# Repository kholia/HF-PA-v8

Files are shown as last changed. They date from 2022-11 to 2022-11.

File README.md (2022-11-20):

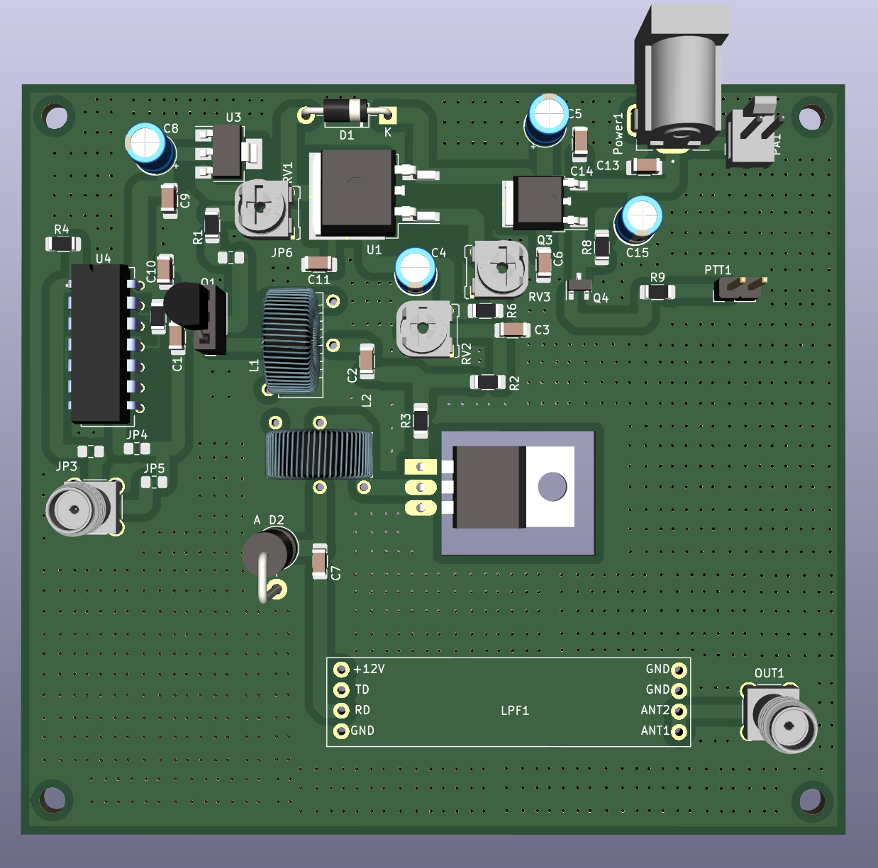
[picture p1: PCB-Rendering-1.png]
PCB Rendering


This work improves upon https://github.com/kholia/HF-PA-v6.

Central idea:

When driven by a Si5351 directly, the output of BS170 is mere 7 to 8 Vpp at 28
MHz.

When driven by a hex-inverter, the output of BS170 easily reaches 13 Vpp at 28
MHz.

This higher BS170 driver output is likely to produce better results (more power
and efficiency) from the IRF510 final @ 28 MHz.

Long-term TODO: Convert all components to SMD. The legs of the THT components
can be bent and fit on top of SMD pads!

- Pots - Bend legs

- Hex-inverter - Get the SMD version of the SN74ACT04N IC.

- BS170 - Bend legs

- Toroids - Bent the leads, stabilize using RTV silicone glue

- Electrolytic caps - Use SMD electrolytic caps

- Diode - Use SMD diode or bend the leads

- PTT - Use SMT pin header, if available?

With this technique the bottom of the PCB will be all ground. This makes
mounting the heat sink an easier problem.

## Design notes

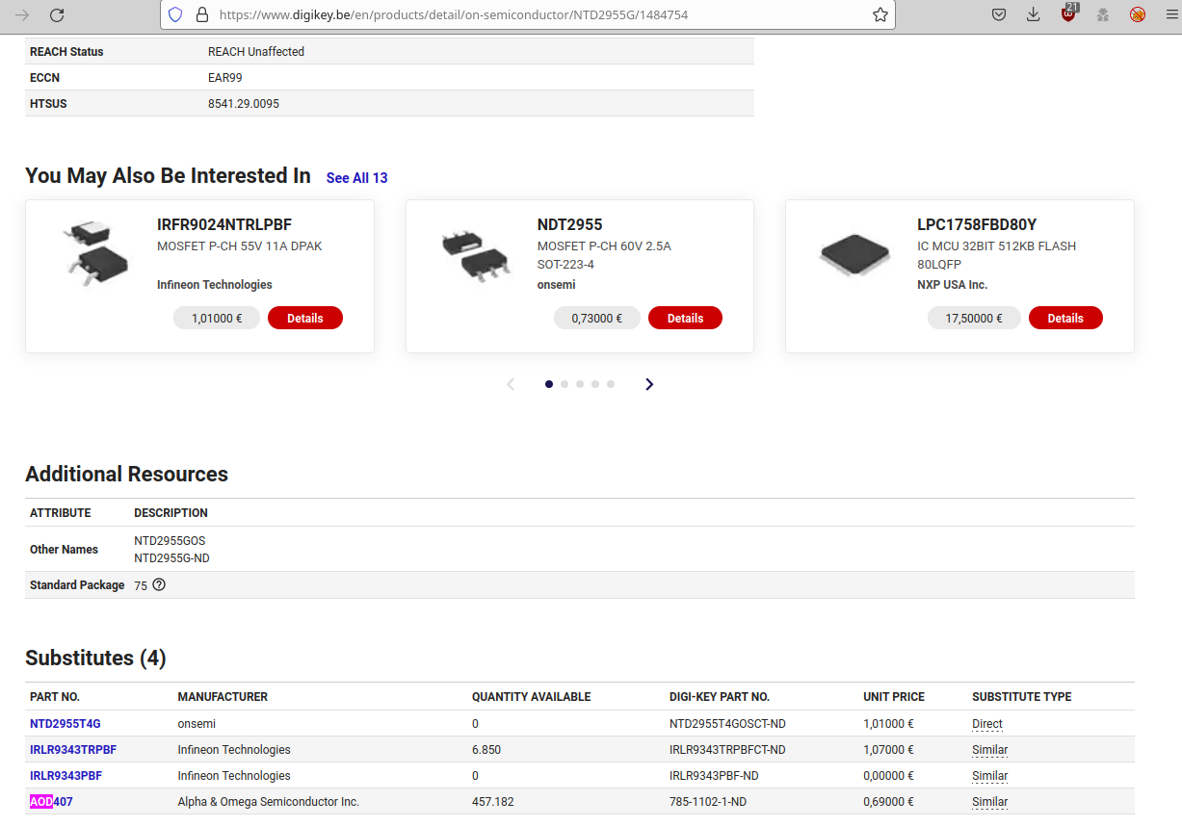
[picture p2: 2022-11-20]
info/Screenshot_2022-11-07_18-18-30.png

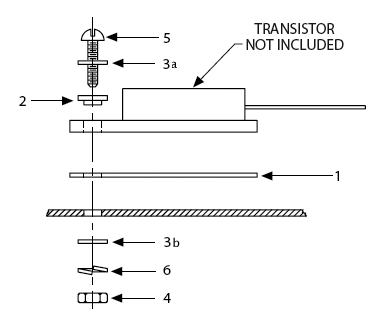
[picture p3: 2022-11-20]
Heat-Sinking/heatsinkmtg.gif

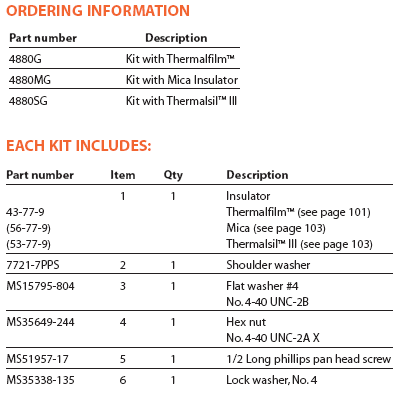
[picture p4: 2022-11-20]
Heat-Sinking/heatsinkmtgparts.gif

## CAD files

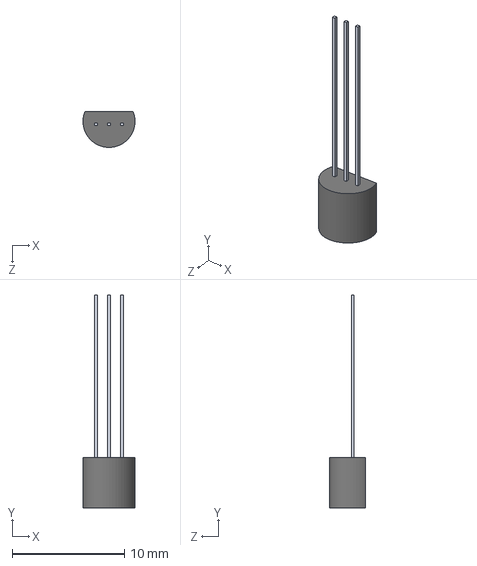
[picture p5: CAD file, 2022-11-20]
models/Transistor_TO-92_Type.STEP
4.64 x 19.0 x 3.20 mm

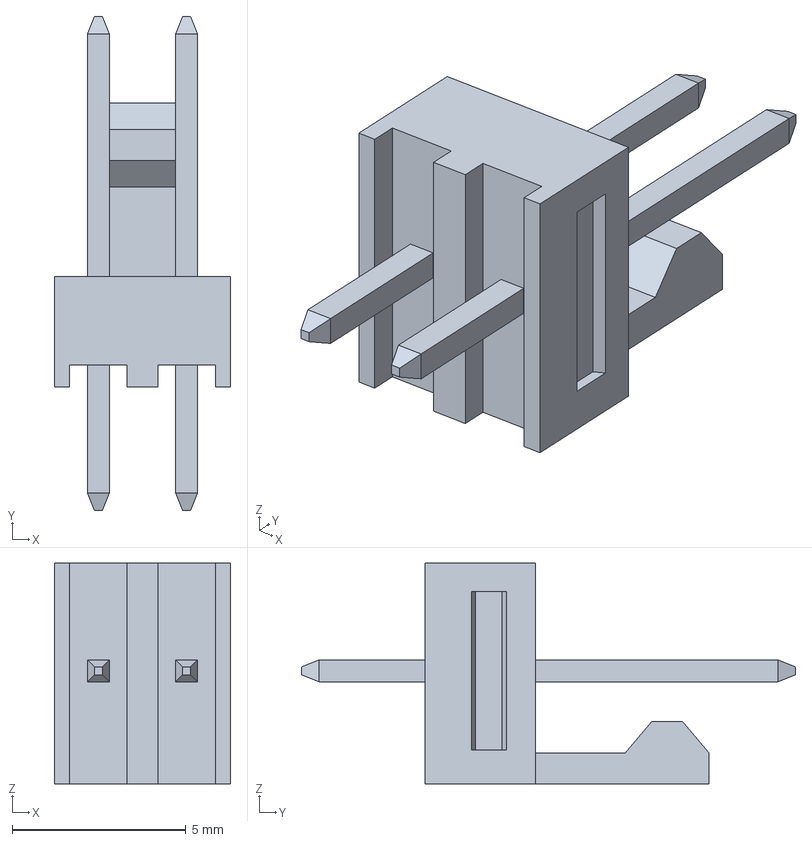
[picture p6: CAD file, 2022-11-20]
models/22-23-2021.stp
5.08 x 14.2 x 6.35 mm

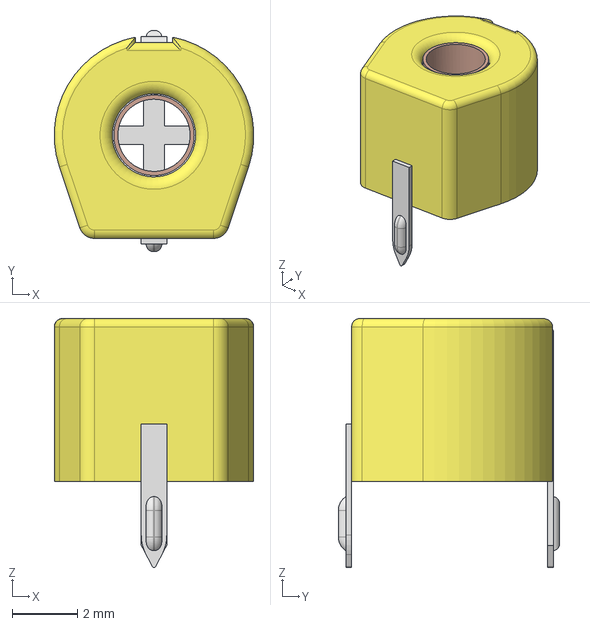
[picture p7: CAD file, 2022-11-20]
models/Trimmer Cap - Yellow.stp
6.09 x 6.76 x 7.61 mm

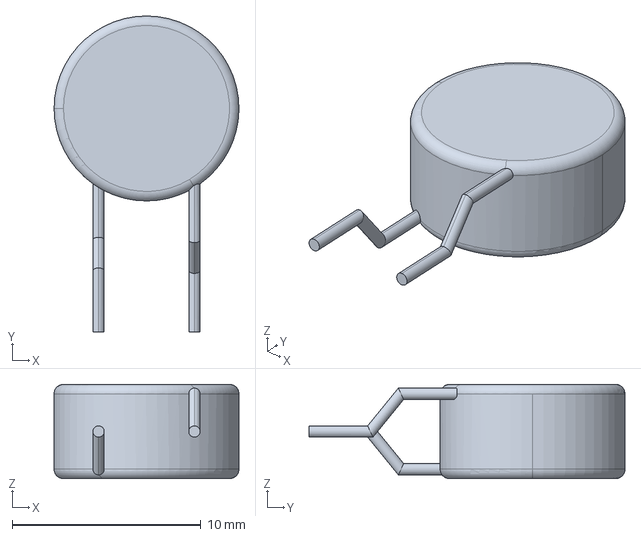
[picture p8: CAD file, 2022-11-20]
models/cmf-rl35.stp
9.80 x 16.8 x 5.00 mm

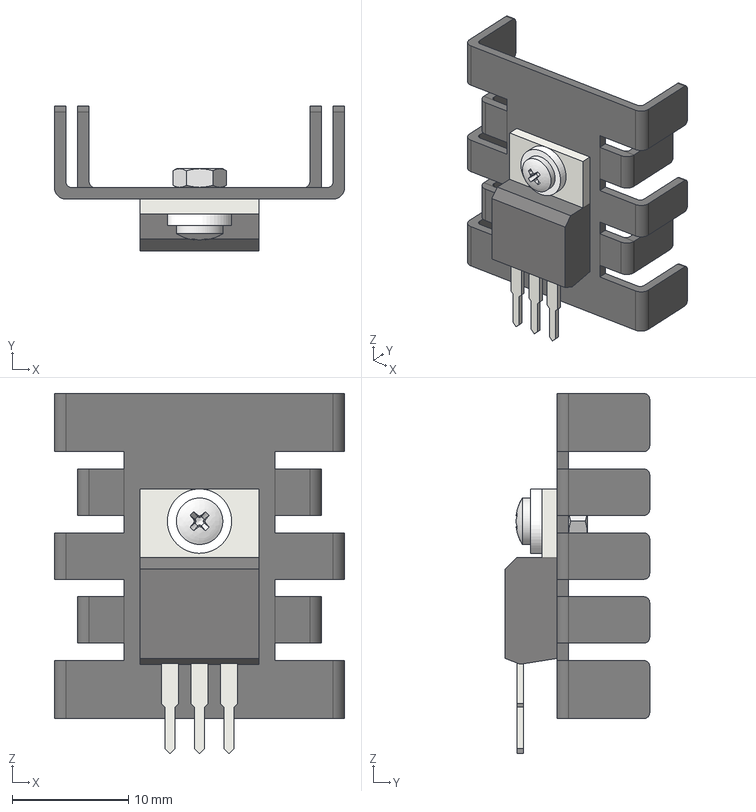
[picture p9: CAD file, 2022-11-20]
models/Heatsink TO-220 28x25x8mm.stp
25.0 x 12.4 x 31.0 mm
TO-220_3_Vertical
Isolator
Screw
Nut
Heatsink_28x25x8mm

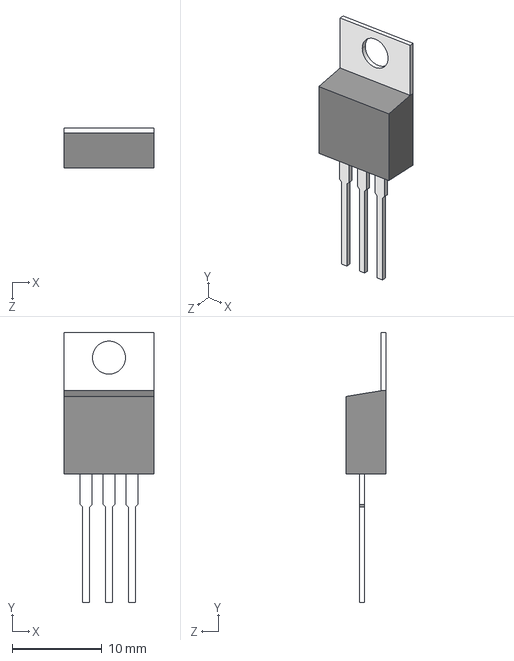
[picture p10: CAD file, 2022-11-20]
models/LM7805CT_NOPB.step
9.97 x 30.0 x 4.44 mm

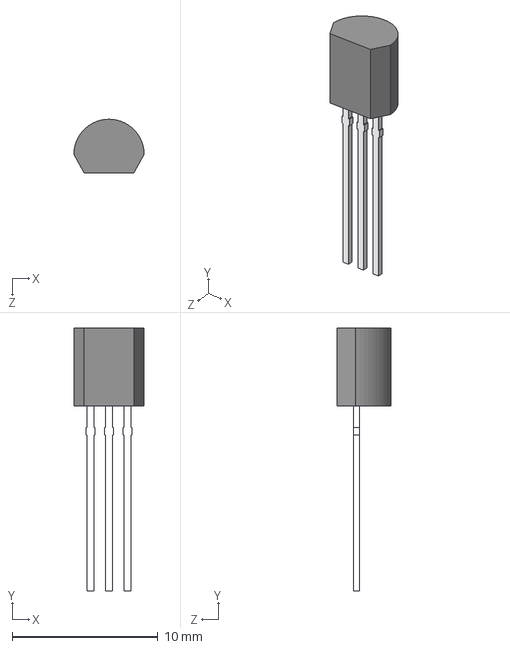
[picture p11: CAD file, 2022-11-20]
models/LM78L05ACZ_NOPB.step
4.83 x 18.0 x 3.68 mm

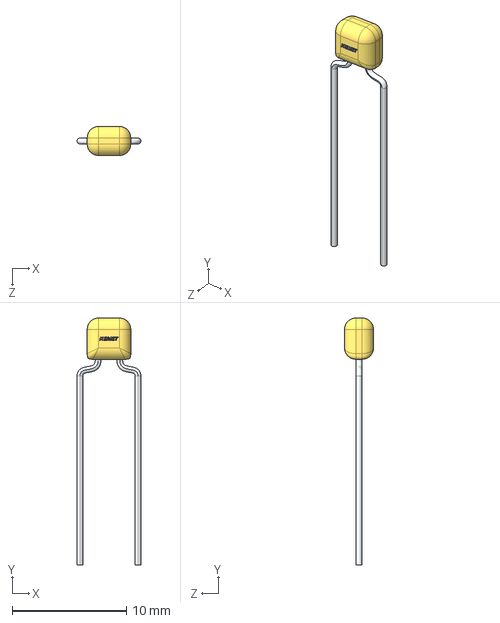
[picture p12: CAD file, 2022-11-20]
models/C317C104K1R5TA7301.step
5.59 x 21.6 x 2.54 mm

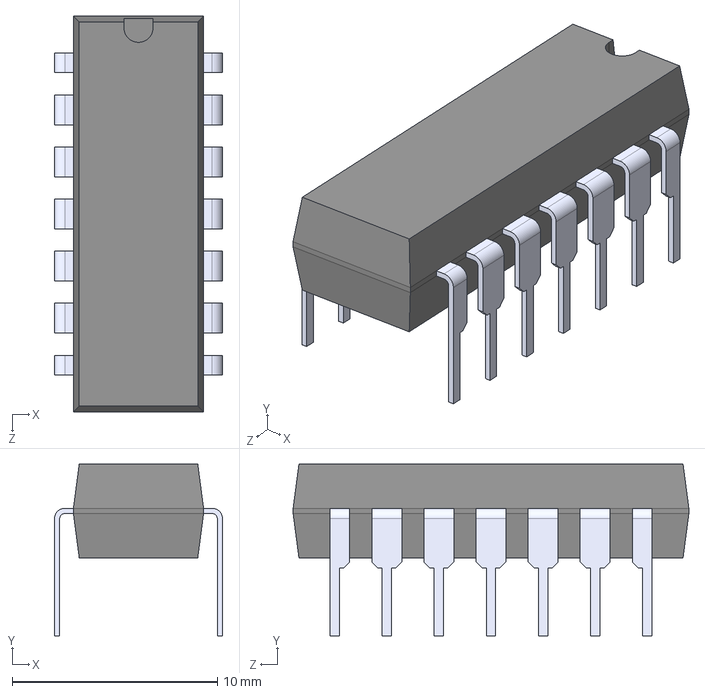
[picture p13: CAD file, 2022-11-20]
models/SN74HC04N.step
8.19 x 8.38 x 19.3 mm

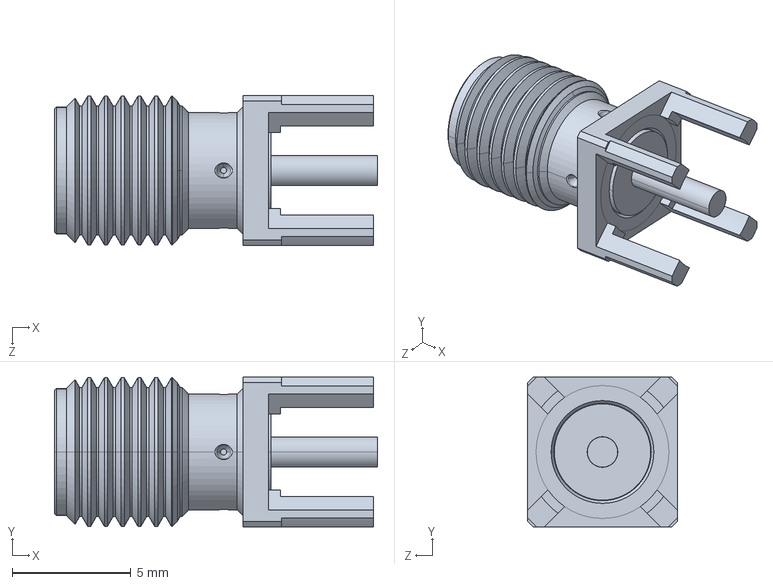
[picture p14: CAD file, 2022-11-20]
models/R125.426.000 D.STEP
13.6 x 6.31 x 6.31 mm

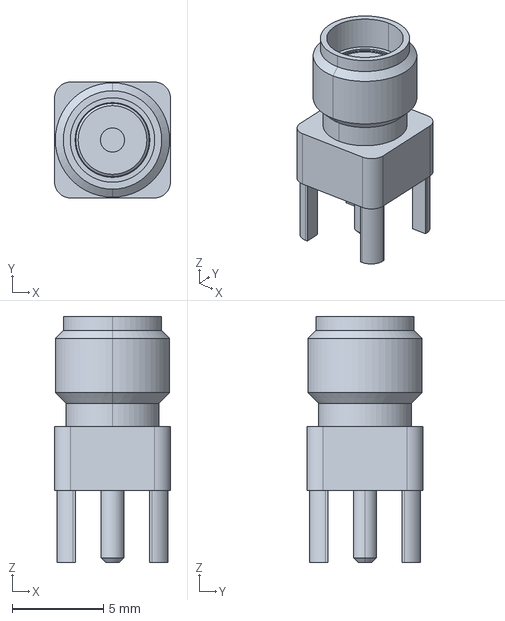
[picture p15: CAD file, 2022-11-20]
models/c-221789-1-e-3d.stp
6.35 x 6.35 x 13.5 mm

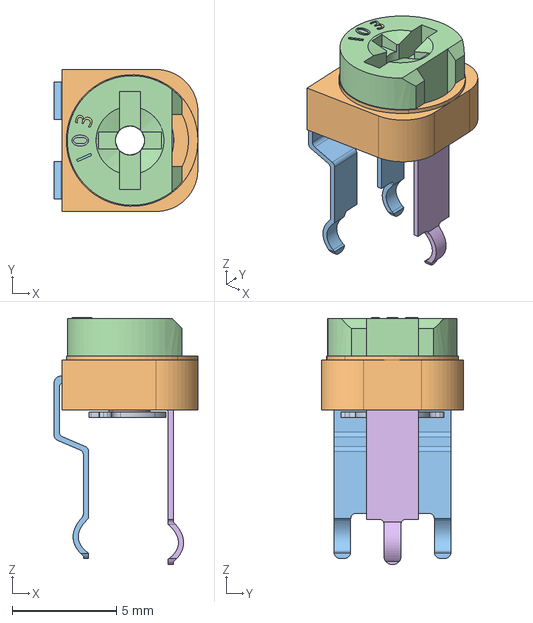
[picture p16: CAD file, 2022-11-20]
models/Poti_10kohm.stp
6.88 x 6.80 x 11.8 mm

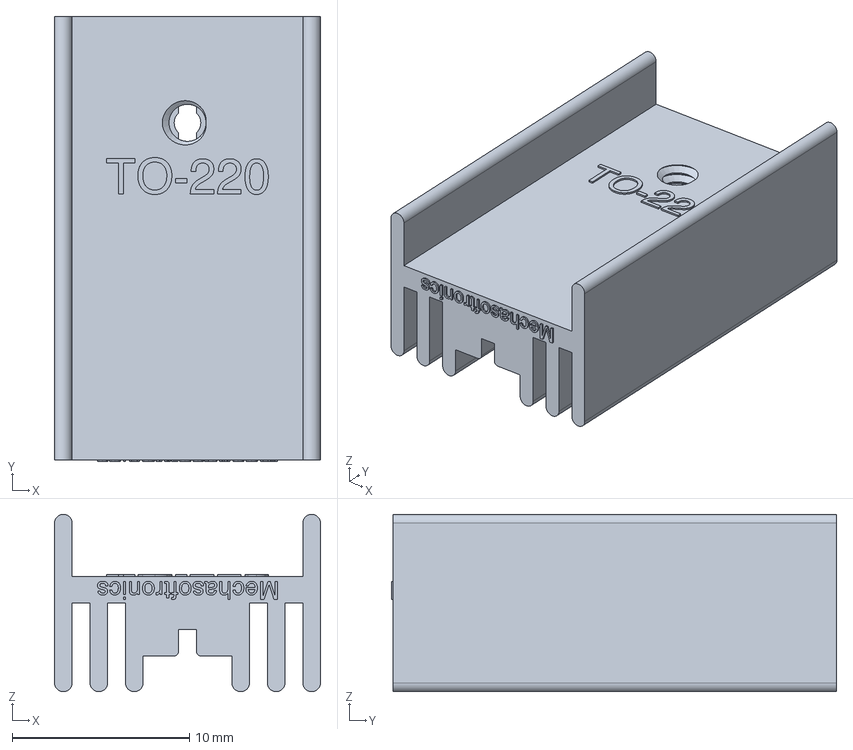
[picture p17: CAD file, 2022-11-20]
models/heatsink_to-220.stp
15.0 x 25.1 x 10.0 mm

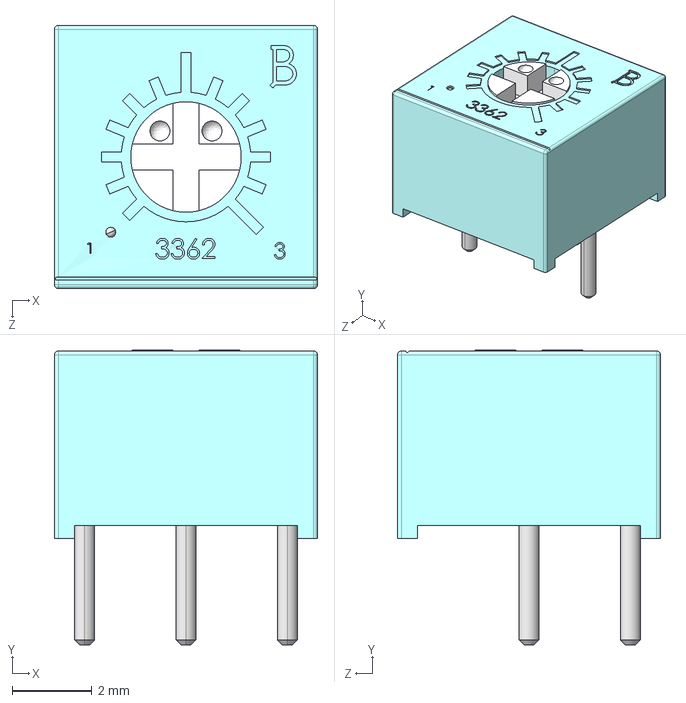
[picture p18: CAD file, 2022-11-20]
models/3362P-1-102LF.STEP
6.60 x 7.40 x 6.60 mm

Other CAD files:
models/Trimmer Cap - Green.stp
models/901-144.stp
models/User Library-TO-92-2_54-line.STEP
models/DC inductor.stl
models/577102B00000.STEP
models/DC-005-5A-2.0.step

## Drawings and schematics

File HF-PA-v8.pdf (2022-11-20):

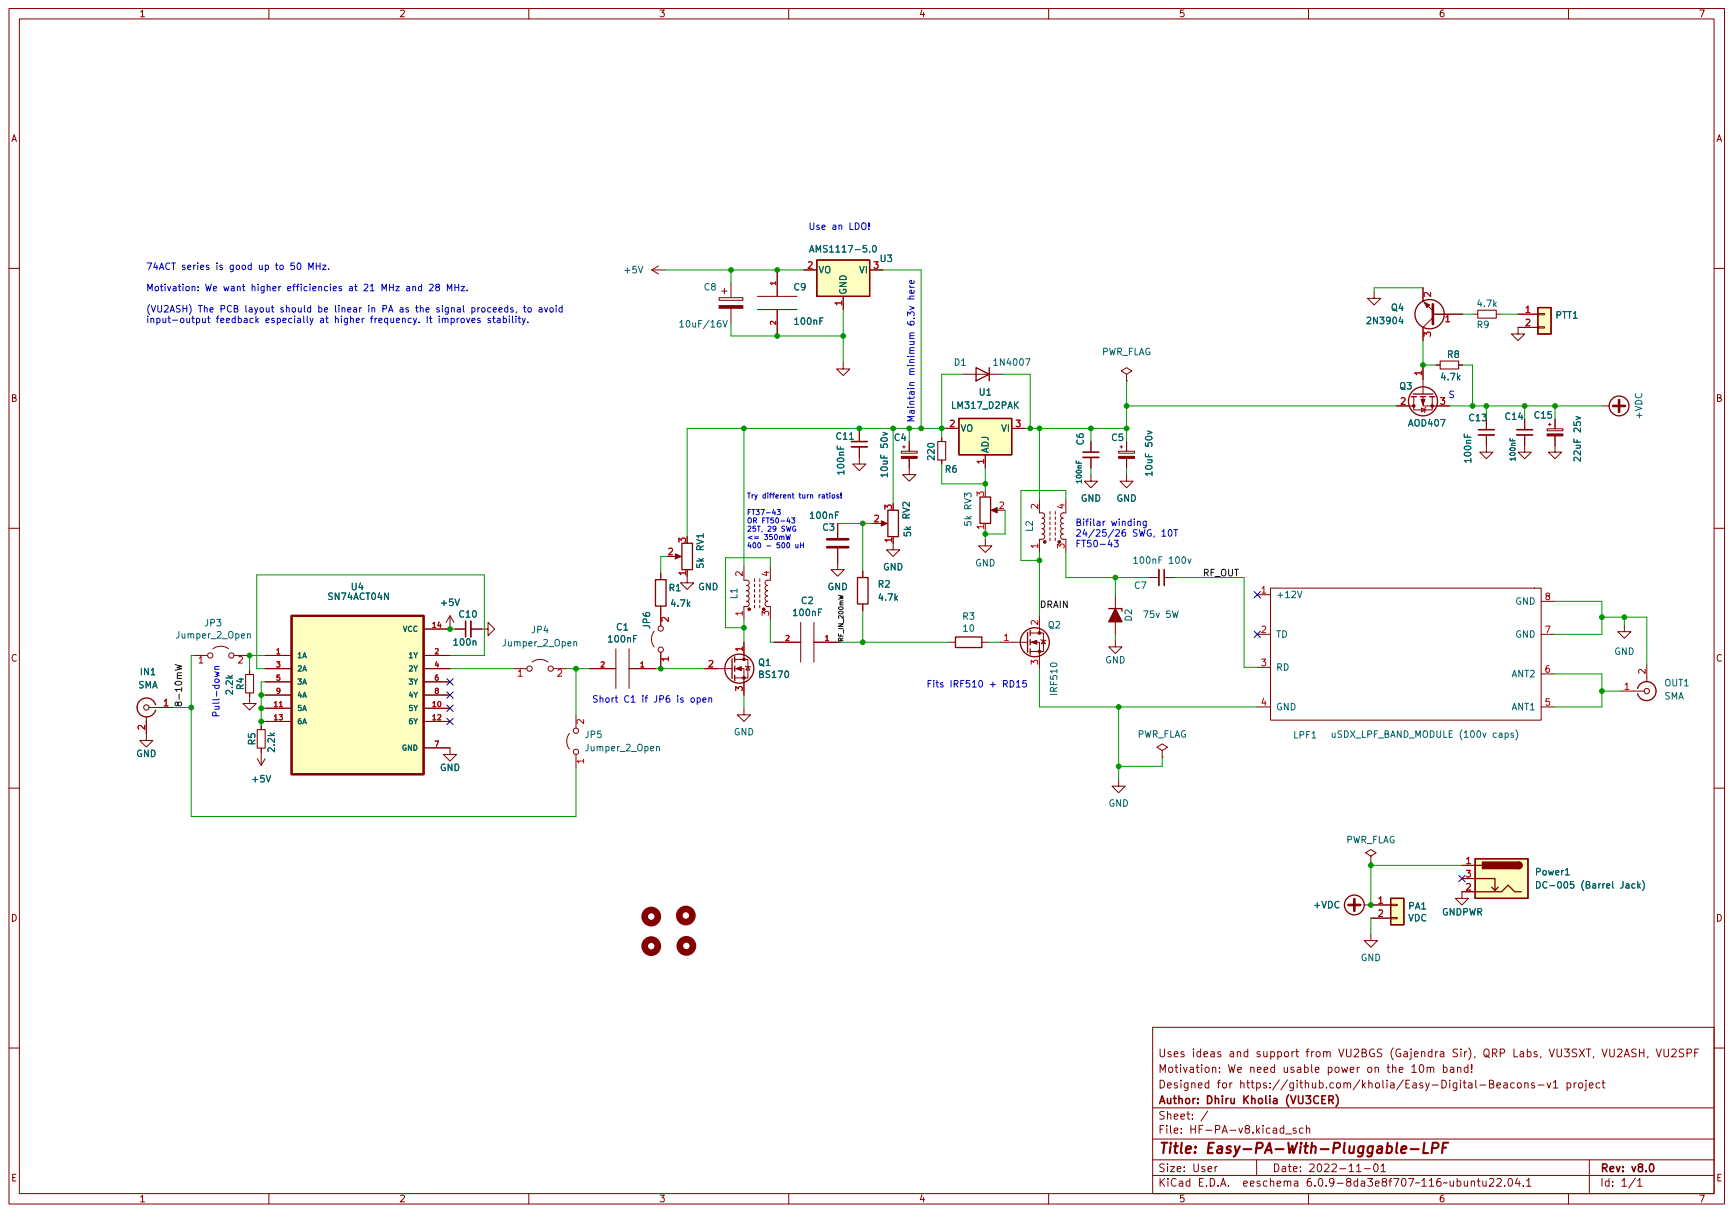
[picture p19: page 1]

74ACT series is good up to 50 MHz.

Motivation: We want higher efficiencies at 21 MHz and 28 MHz.

(VU2ASH) The PCB layout should be linear in PA as the signal proceeds, to avoid

Try different turn ratios! FT37-43 OR FT50-43

Short C1 if JP6 is open

Uses ideas and support from VU2BGS (Gajendra Sir), QRP Labs, VU3SXT, VU2ASH, VU2SPF
Motivation: We need usable power on the 10m band!
Designed for https://github.com/kholia/Easy-Digital-Beacons-v1 project
File: HF-PA-v8.kicad_sch Sheet: / Author: Dhiru Kholia (VU3CER)

Id: 1/1 Title: Easy-PA-With-Pluggable-LPF

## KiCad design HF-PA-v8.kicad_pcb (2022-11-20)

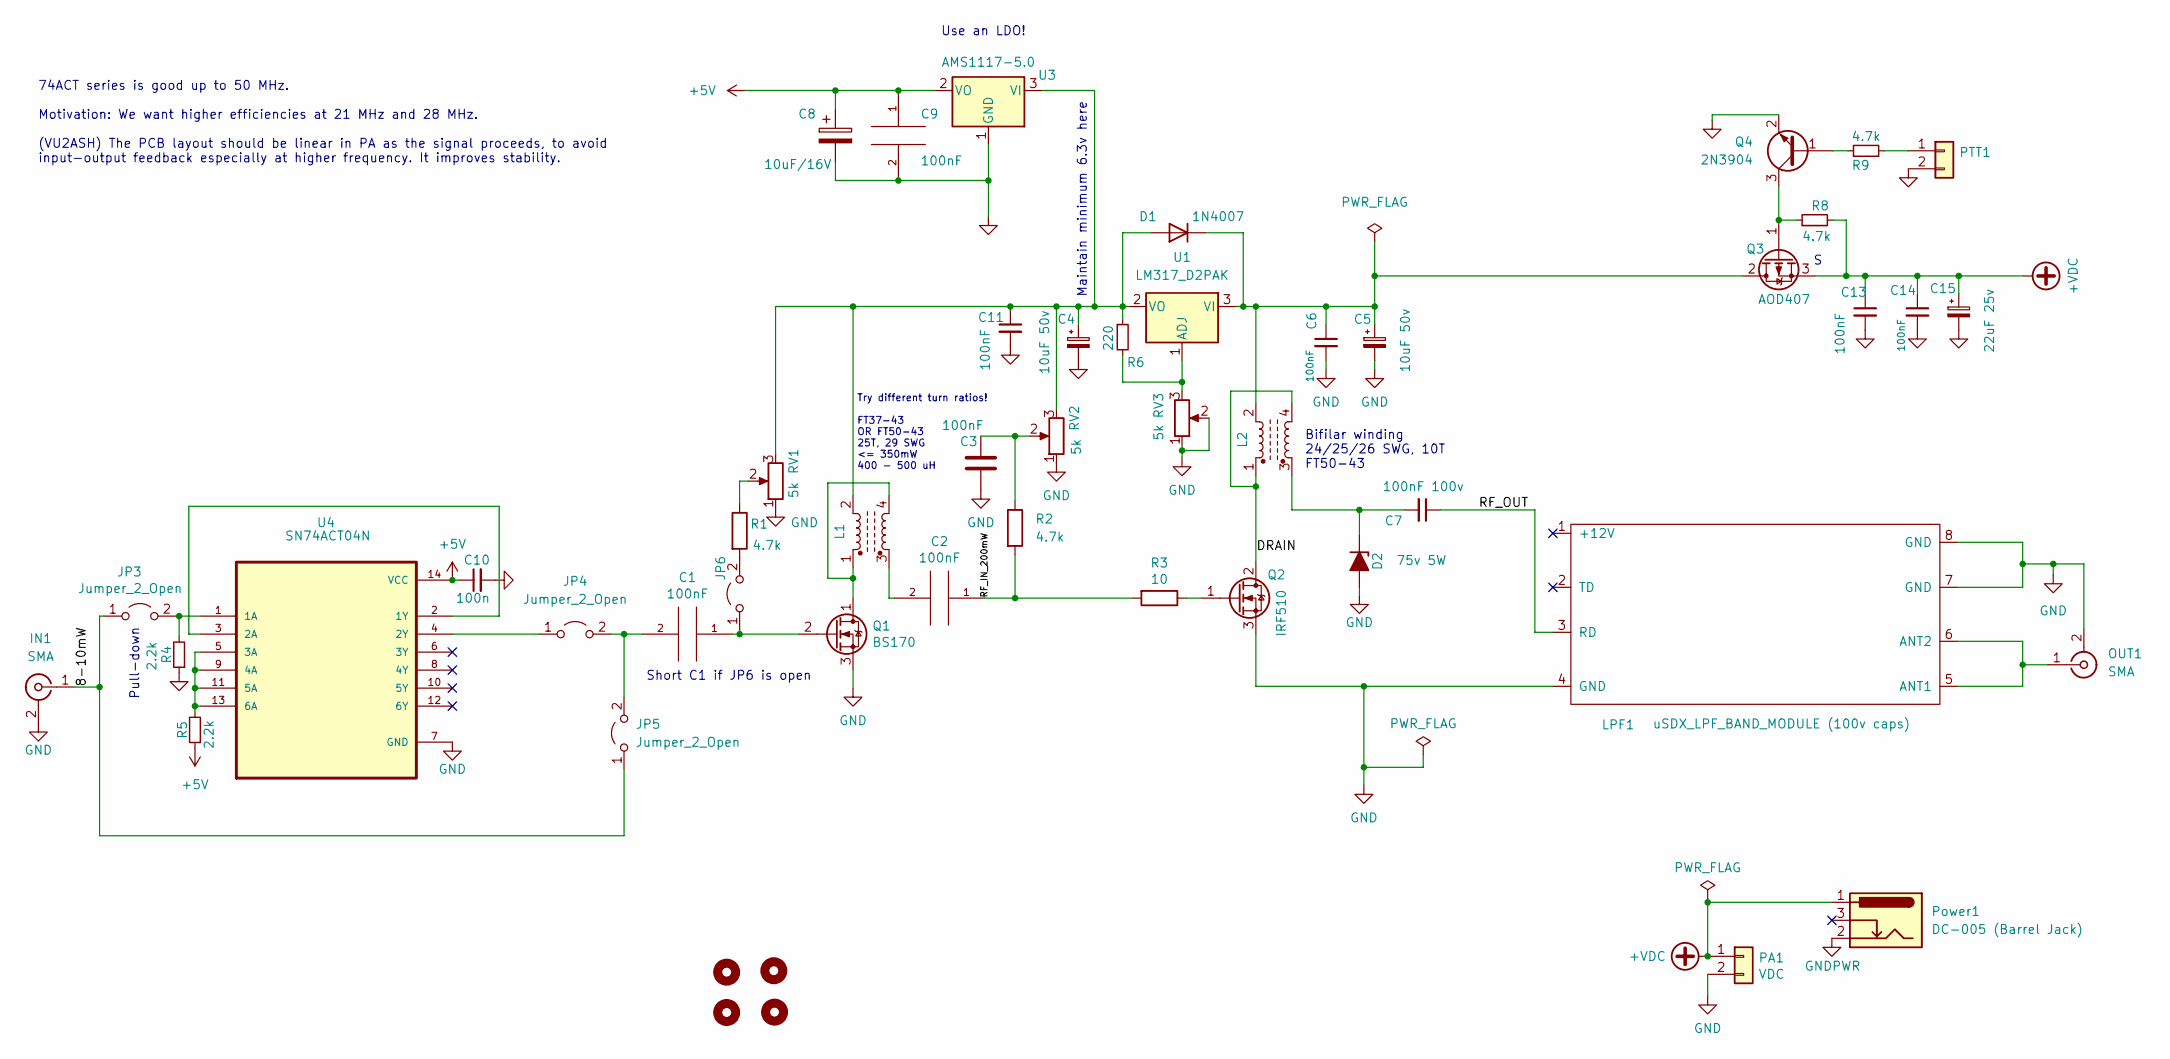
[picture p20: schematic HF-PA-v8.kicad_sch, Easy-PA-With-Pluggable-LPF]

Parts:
C1, C2, C3, C6, C9, C11, C13, C14: 100nF; C_1206_3216Metric_Pad1.33x1.80mm_HandSolder
C4, C5: 10uF 50v; CP_Radial_D5.0mm_P2.50mm
C7: 100nF 100v; C_1206_3216Metric_Pad1.33x1.80mm_HandSolder
C8: 10uF/16V; CP_Radial_D5.0mm_P2.50mm
C10: 100n; C_1206_3216Metric_Pad1.33x1.80mm_HandSolder
C15: 22uF 25v; CP_Radial_D5.0mm_P2.50mm
D1: 1N4007; D_DO-41_SOD81_P10.16mm_Horizontal
D2: 75v 5W; D_DO-201_P5.08mm_Vertical_KathodeUp
H1, H2, H3, H4: MountingHole; MountingHole_3.2mm_M3
IN1: SMA; SMA_Amphenol_901-144_Vertical
JP3, JP4, JP5, JP6: Jumper_2_Open; C_0805_2012Metric_Pad1.18x1.45mm_HandSolder
L1, L2: L_Ferrite_Coupled; FT50-43 Transformer
LPF1: uSDX_LPF_BAND_MODULE (100v caps); uSDX_LPF_Band_Module
OUT1: SMA; SMA_Amphenol_901-144_Vertical
PA1: VDC; PinHeader_1x02_P2.54mm_Vertical
PTT1: PTT; PinHeader_1x02_P2.54mm_Vertical
Power1: DC-005 (Barrel Jack); XKB_DC-005-5A-2.0_Modded
Q1: BS170; PinSocket_1x03_P2.54mm_Vertical
Q2: IRF510; TO-220-3_Horizontal_TabDown
Q3: AOD407; TO-252-2
Q4: 2N3904; SOT-23
R1, R2, R8, R9: 4.7k; R_1206_3216Metric_Pad1.30x1.75mm_HandSolder
R3: 10; R_1206_3216Metric_Pad1.30x1.75mm_HandSolder
R4, R5: 2.2k; R_1206_3216Metric_Pad1.30x1.75mm_HandSolder
R6: 220; R_1206_3216Metric_Pad1.30x1.75mm_HandSolder
RV1, RV2, RV3: 5k; Potentiometer_Runtron_RM-065_Vertical
U1: LM317_D2PAK; TO-263-2
U3: AMS1117-5.0; SOT-223-3_TabPin2
U4: SN74ACT04N; DIP794W45P254L1969H508Q14

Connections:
+5V: C8.1, C9.1, C10.1, R5.1, U3.2 (VO), U4.14 (VCC)
+VDC: C13.1, C14.1, C15.1, PA1.1, Power1.1, Q3.3 (S), R8.2
/8-10mW: IN1.1 (In), JP3.1 (A), JP5.1 (A)
/DRAIN: L2.1, L2.4, Q2.2 (D)
/RF_IN_200mW: C2.1, R2.2, R3.2
/RF_OUT: C7.1, LPF1.3 (RD)
unnamed: C1.1, JP6.1 (A), Q1.2 (G)
unnamed: C1.2, JP4.2 (B), JP5.2 (B)
unnamed: C2.2, L1.3
unnamed: C3.1, R2.1, RV2.2
unnamed: C5.1, C6.1, D1.1 (K), L2.2, Q3.2 (D), U1.3 (VI)
unnamed: C7.2, D2.1 (K), L2.3
unnamed: C4.1, C11.1, D1.2 (A), L1.2, R6.1, RV1.3, RV2.3, U1.2 (VO), U3.3 (VI)
unnamed: JP3.2 (B), R4.2, U4.1 (1A)
unnamed: JP4.1 (A), U4.4 (2Y)
unnamed: JP6.2 (B), R1.2
unnamed: L1.1, L1.4, Q1.1 (D)
unnamed: LPF1.5 (ANT1), LPF1.6 (ANT2), OUT1.1 (In)
unnamed: PTT1.1, R9.2
unnamed: Q2.1 (G), R3.1
unnamed: Q3.1 (G), Q4.3 (C), R8.1
unnamed: Q4.1 (B), R9.1
unnamed: R1.1, RV1.2
unnamed: R5.2, U4.5 (3A), U4.9 (4A), U4.11 (5A), U4.13 (6A)
unnamed: R6.2, RV3.3, U1.1 (ADJ)
unnamed: U4.2 (1Y), U4.3 (2A)

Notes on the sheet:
Maintain minimum 6.3v here
Pull-down
Bifilar winding 24/25/26 SWG, 10T FT50-43
Try different turn ratios! FT37-43 OR FT50-43 25T, 29 SWG <= 350mW 400 - 500 uH
74ACT series is good up to 50 MHz. Motivation: We want higher efficiencies at 21 MHz and 28 MHz. (VU2ASH) The PCB layout should be linear in PA as the signal proceeds, to avoid input-output feedback especially at higher frequency. It improves stability.
Short C1 if JP6 is open
Use an LDO!

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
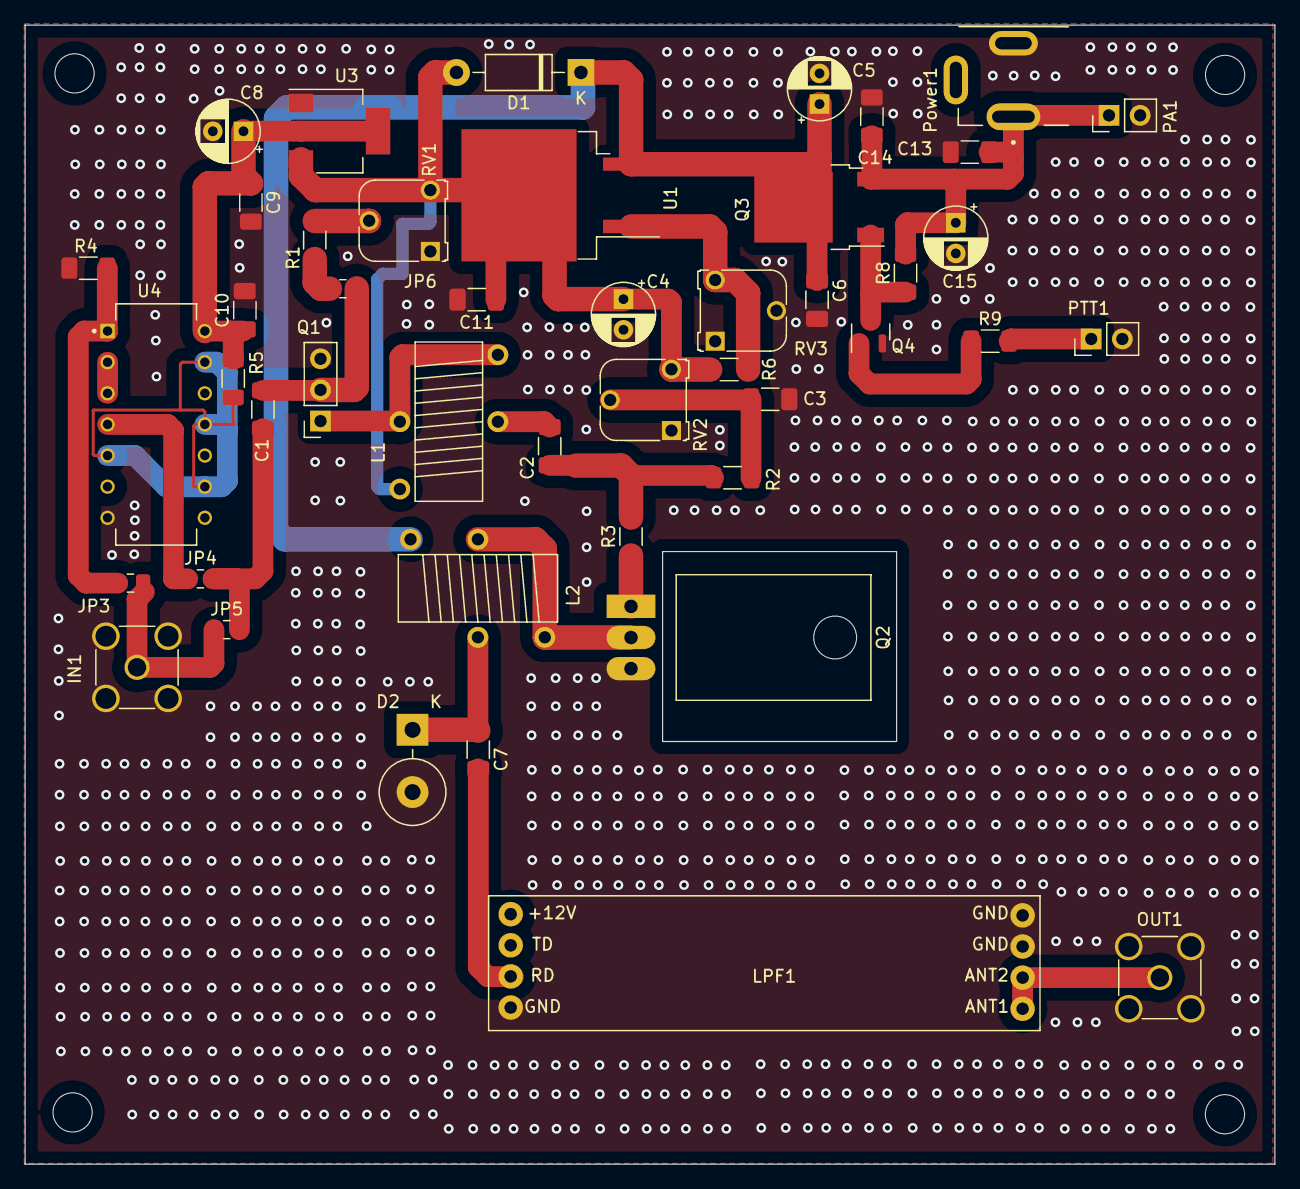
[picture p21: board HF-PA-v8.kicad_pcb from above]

Board: 2 copper layers, 102.0 x 93.0 mm, 50 parts (0 on the bottom side), 27 nets.
